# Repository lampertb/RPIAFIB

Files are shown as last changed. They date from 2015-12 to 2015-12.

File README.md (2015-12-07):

# RPIAFIB
AFIB Detection using Raspberry Pi Compute Module

This is a project created by Yifan Ge and Ben Lampert for the CS241 Embedded Workshop class(http://web.stanford.edu/class/cs241/). The intention is to create an open source AFIB detection wearable which can be used to diagnose patients with the condition.

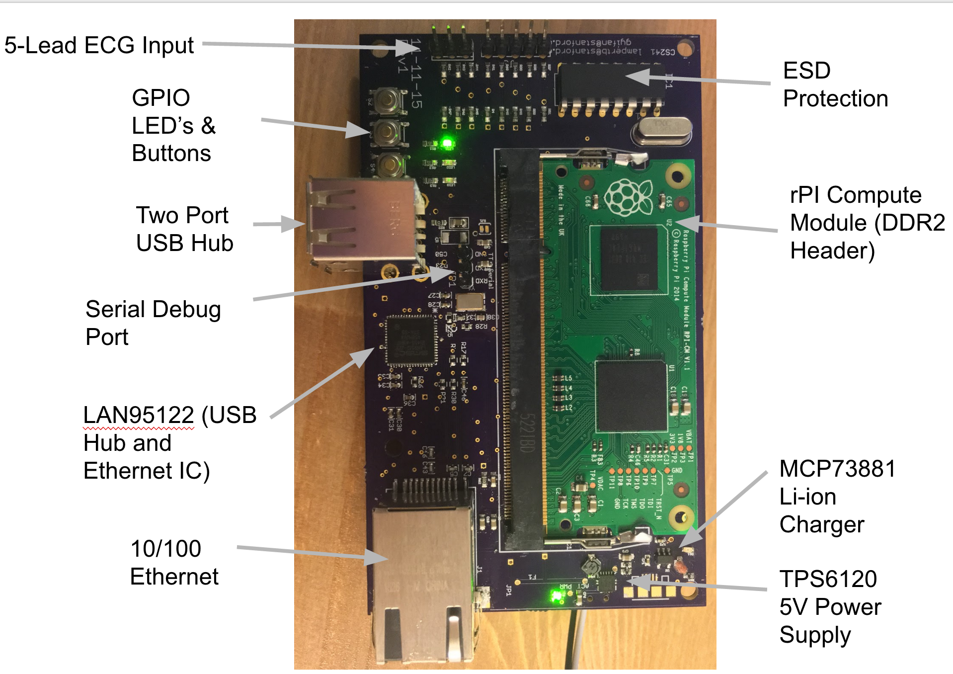
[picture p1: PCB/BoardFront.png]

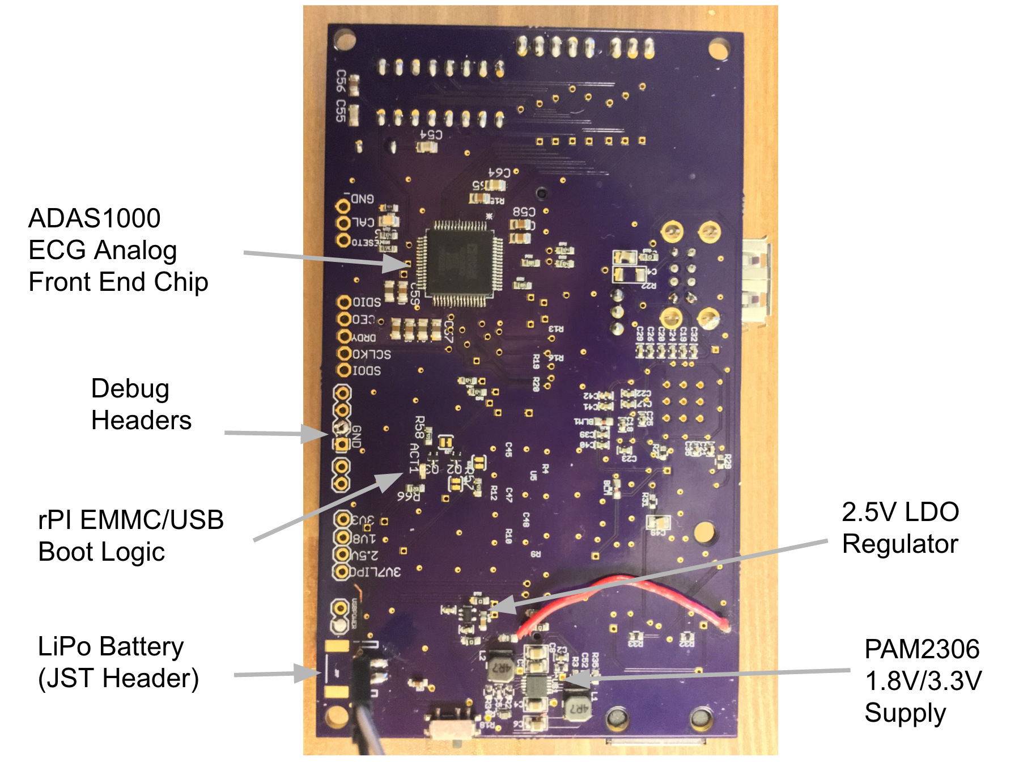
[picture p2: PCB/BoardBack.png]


Please reference the instructable for more information on assembling the board.
http://www.instructables.com/id/rPI-Atrial-Fibrillation-Detection-Board/

To install run

sudo sh ./install.sh

Run software:
cd Software
sudo ./execute_afib_detect

Todo:
Software:
-Improve ECG Capture code
-Improve integration between the algorithm detection and sampling code
Hardware:
-Lipo charger circuit does not allow for the board to be powered while charging the LED, need to find a solution for this. Integrated charger?

USE AT YOUR OWN RISK: This project involves ECG measurements which can be dangerous if not done correctly. It is your responsibility to evaluate your own medical and physical condition, or that of your clients, and to independently determine whether to perform, use or adapt any of the information or content on this repository. By voluntarily undertaking the project displayed on this website, you assume the risk of any resulting injury.

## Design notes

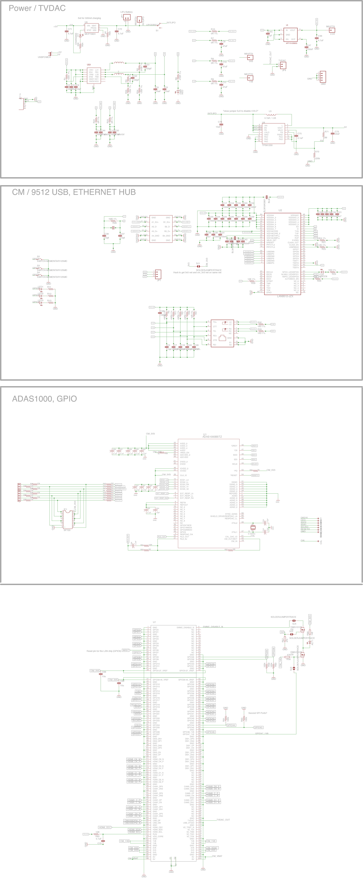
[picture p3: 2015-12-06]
PCB/Schematic.png

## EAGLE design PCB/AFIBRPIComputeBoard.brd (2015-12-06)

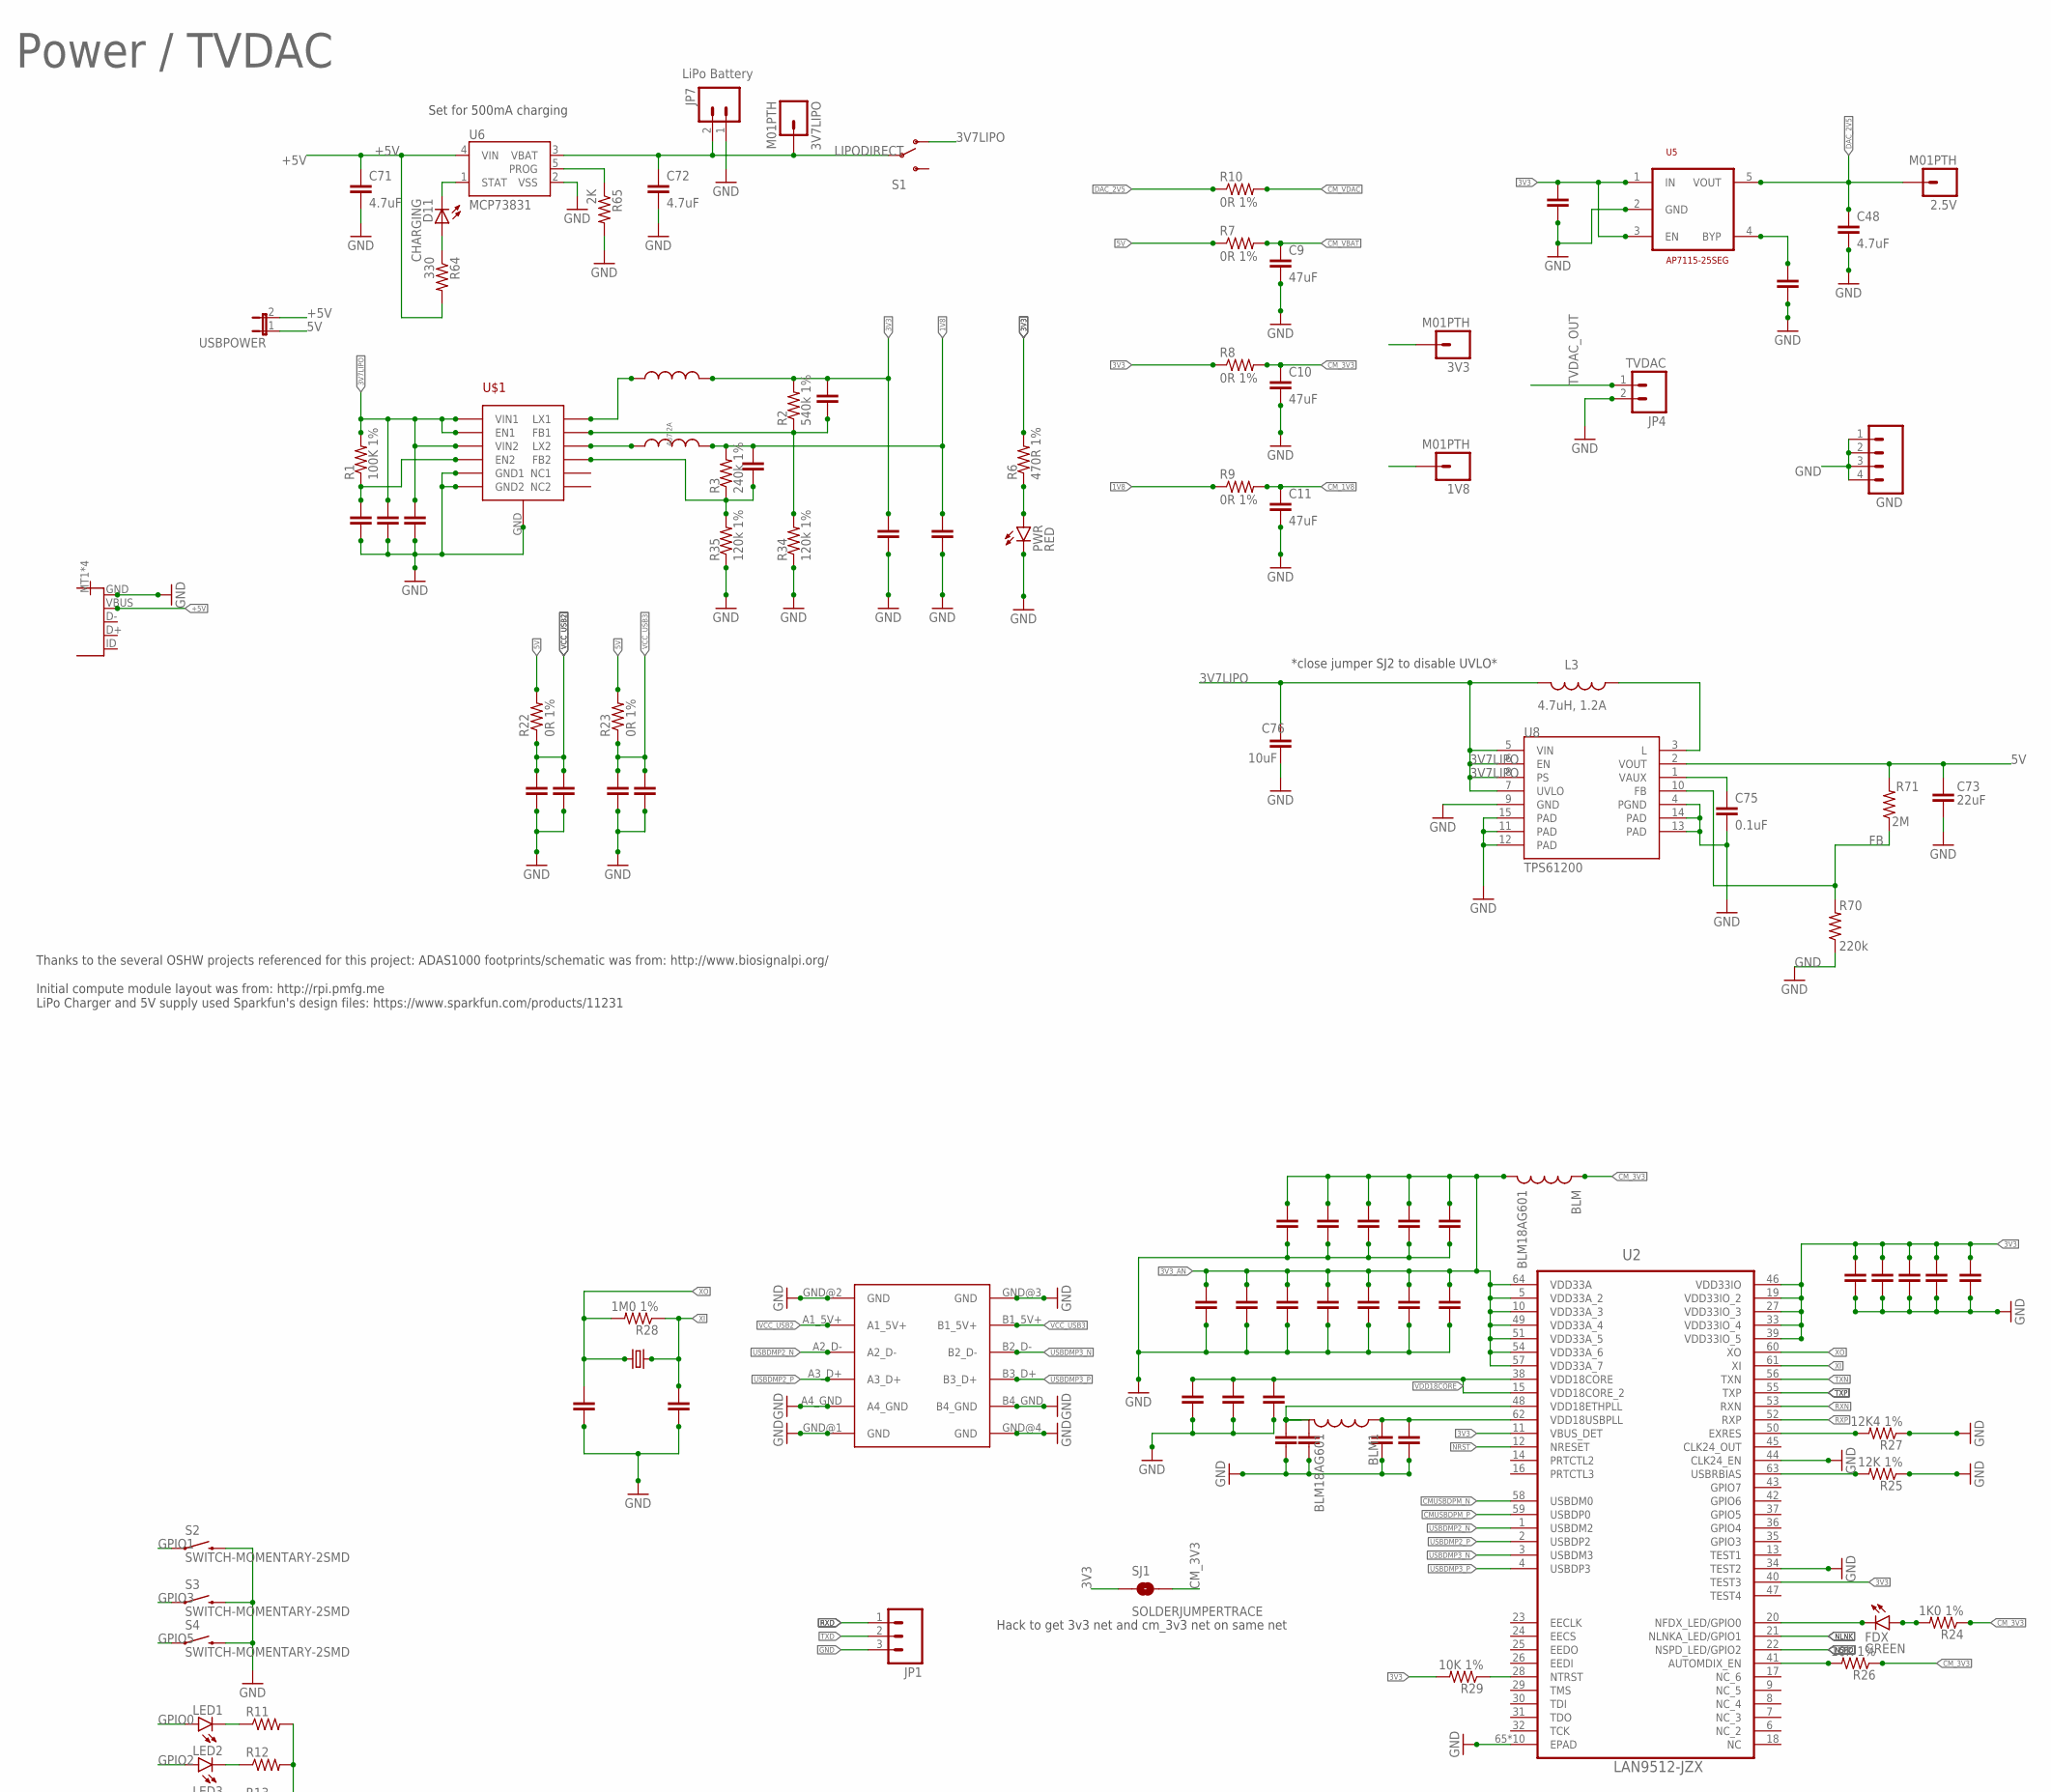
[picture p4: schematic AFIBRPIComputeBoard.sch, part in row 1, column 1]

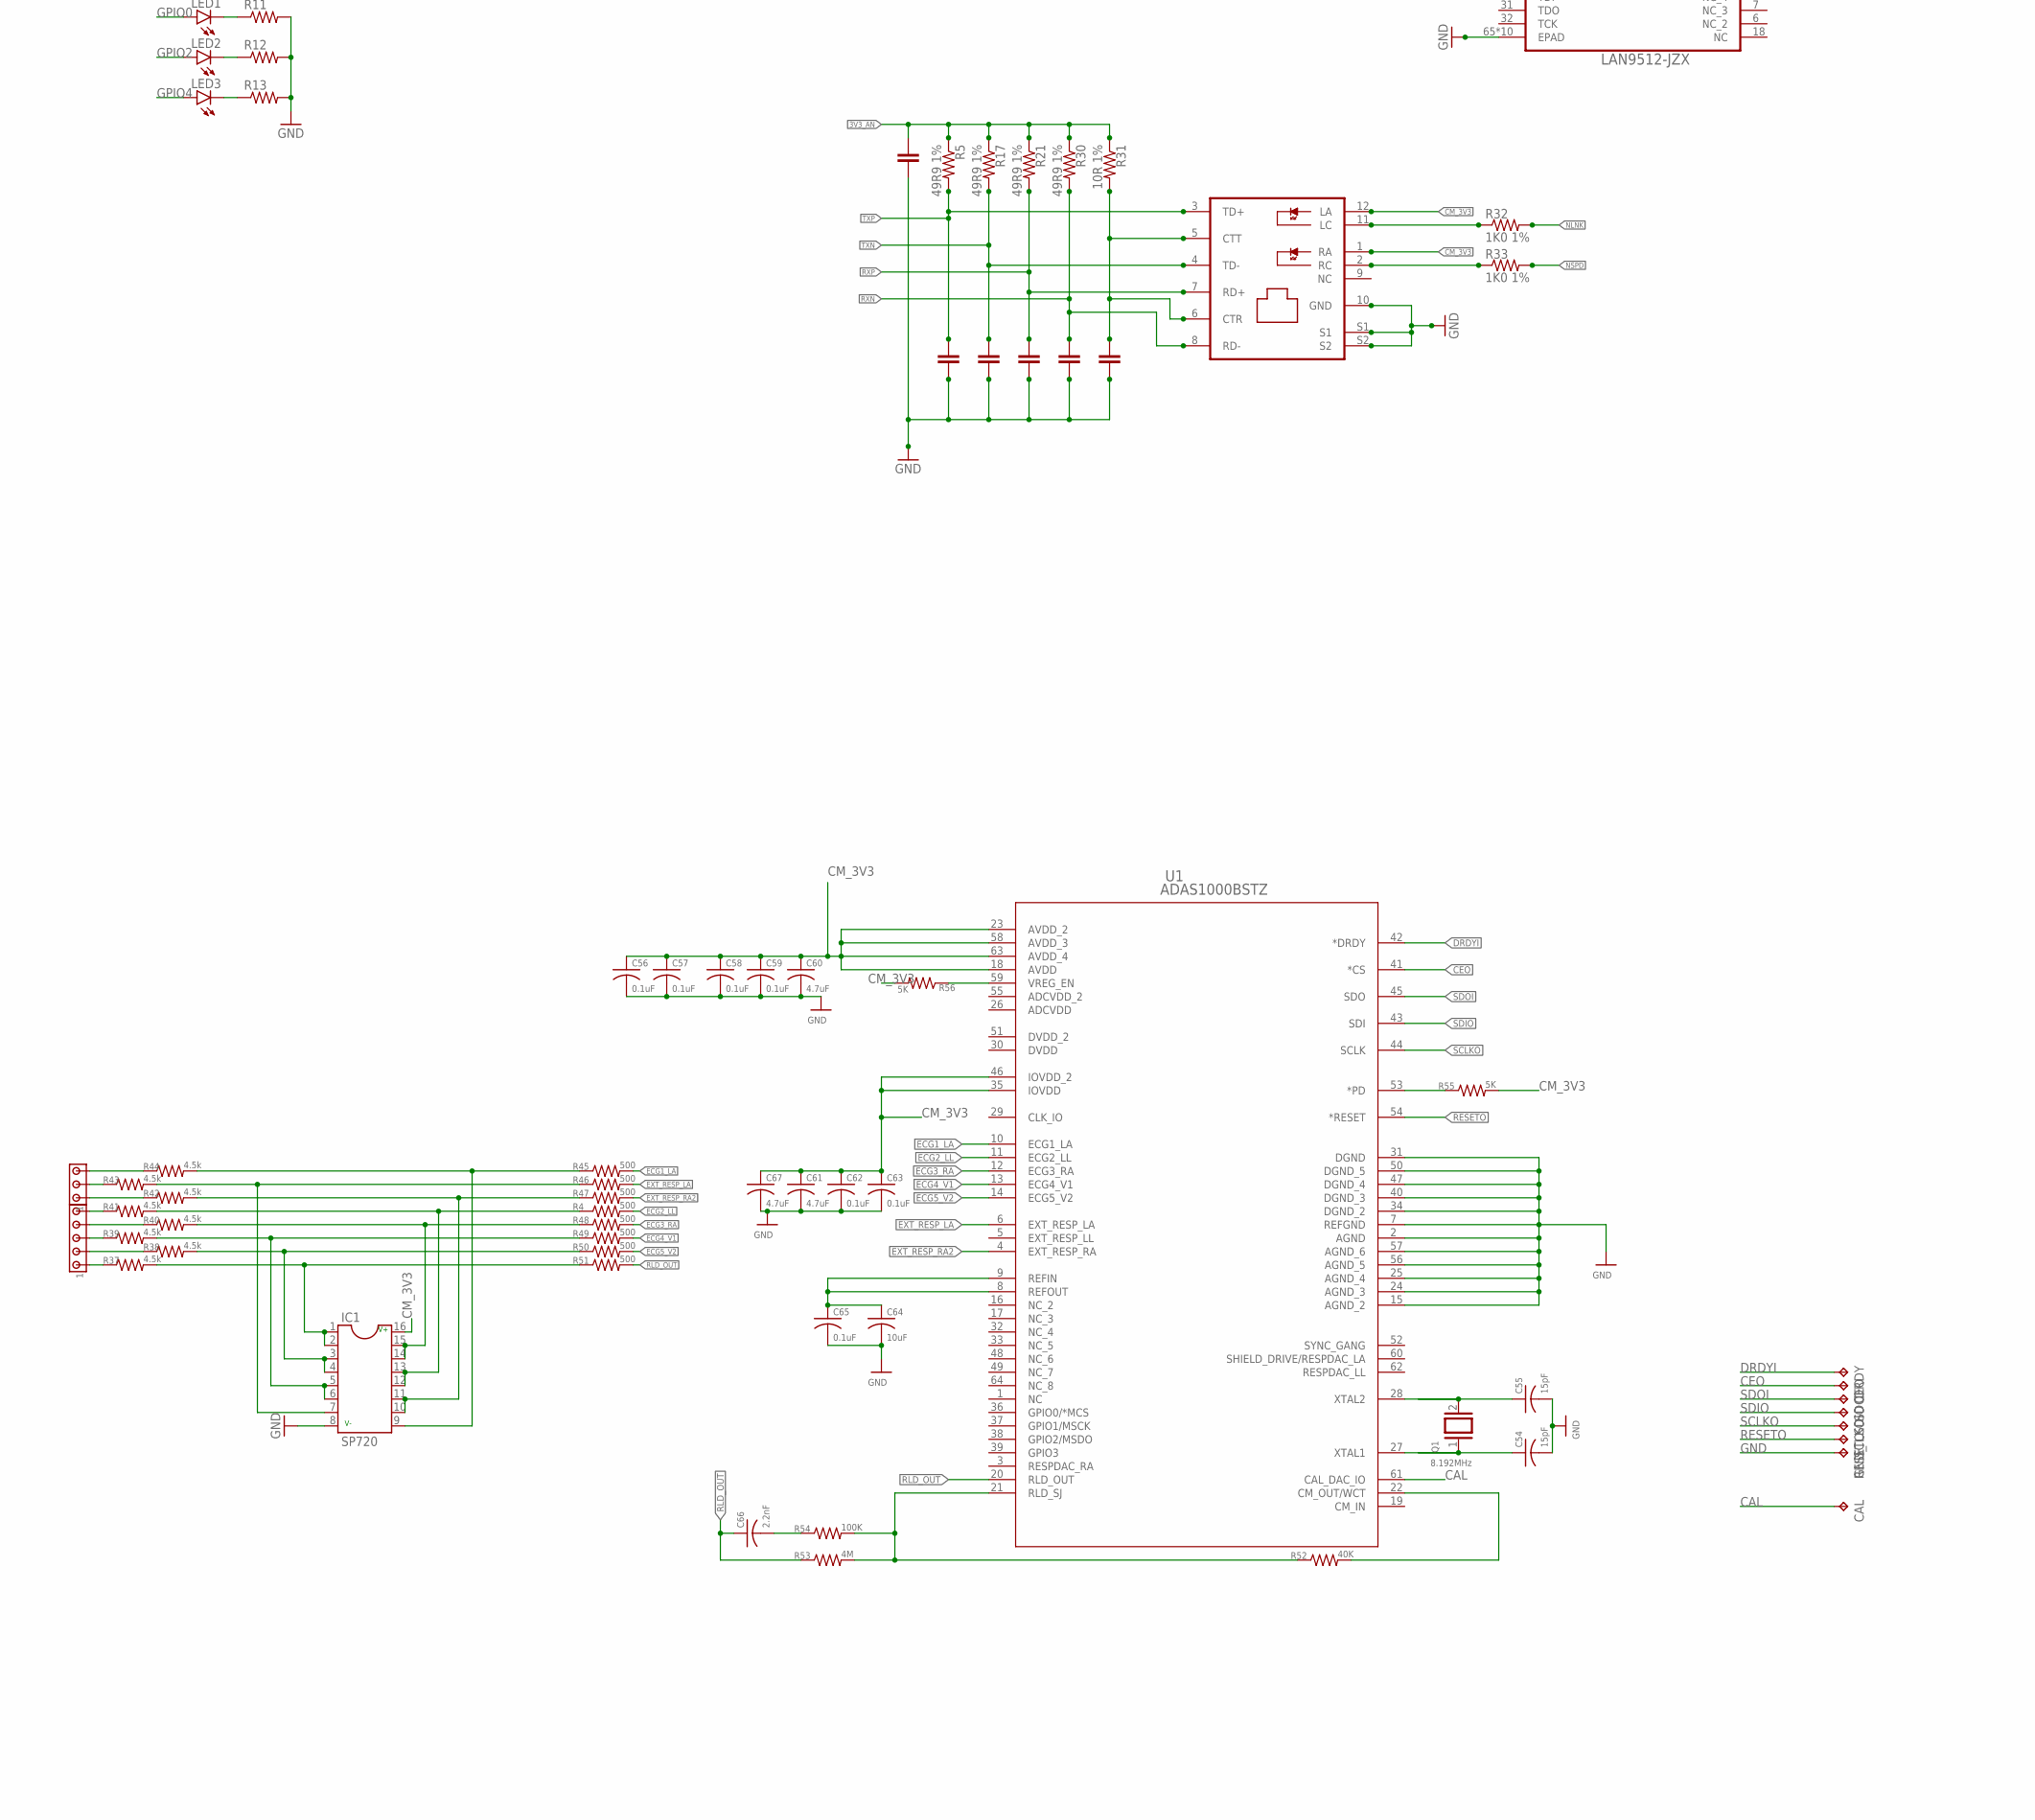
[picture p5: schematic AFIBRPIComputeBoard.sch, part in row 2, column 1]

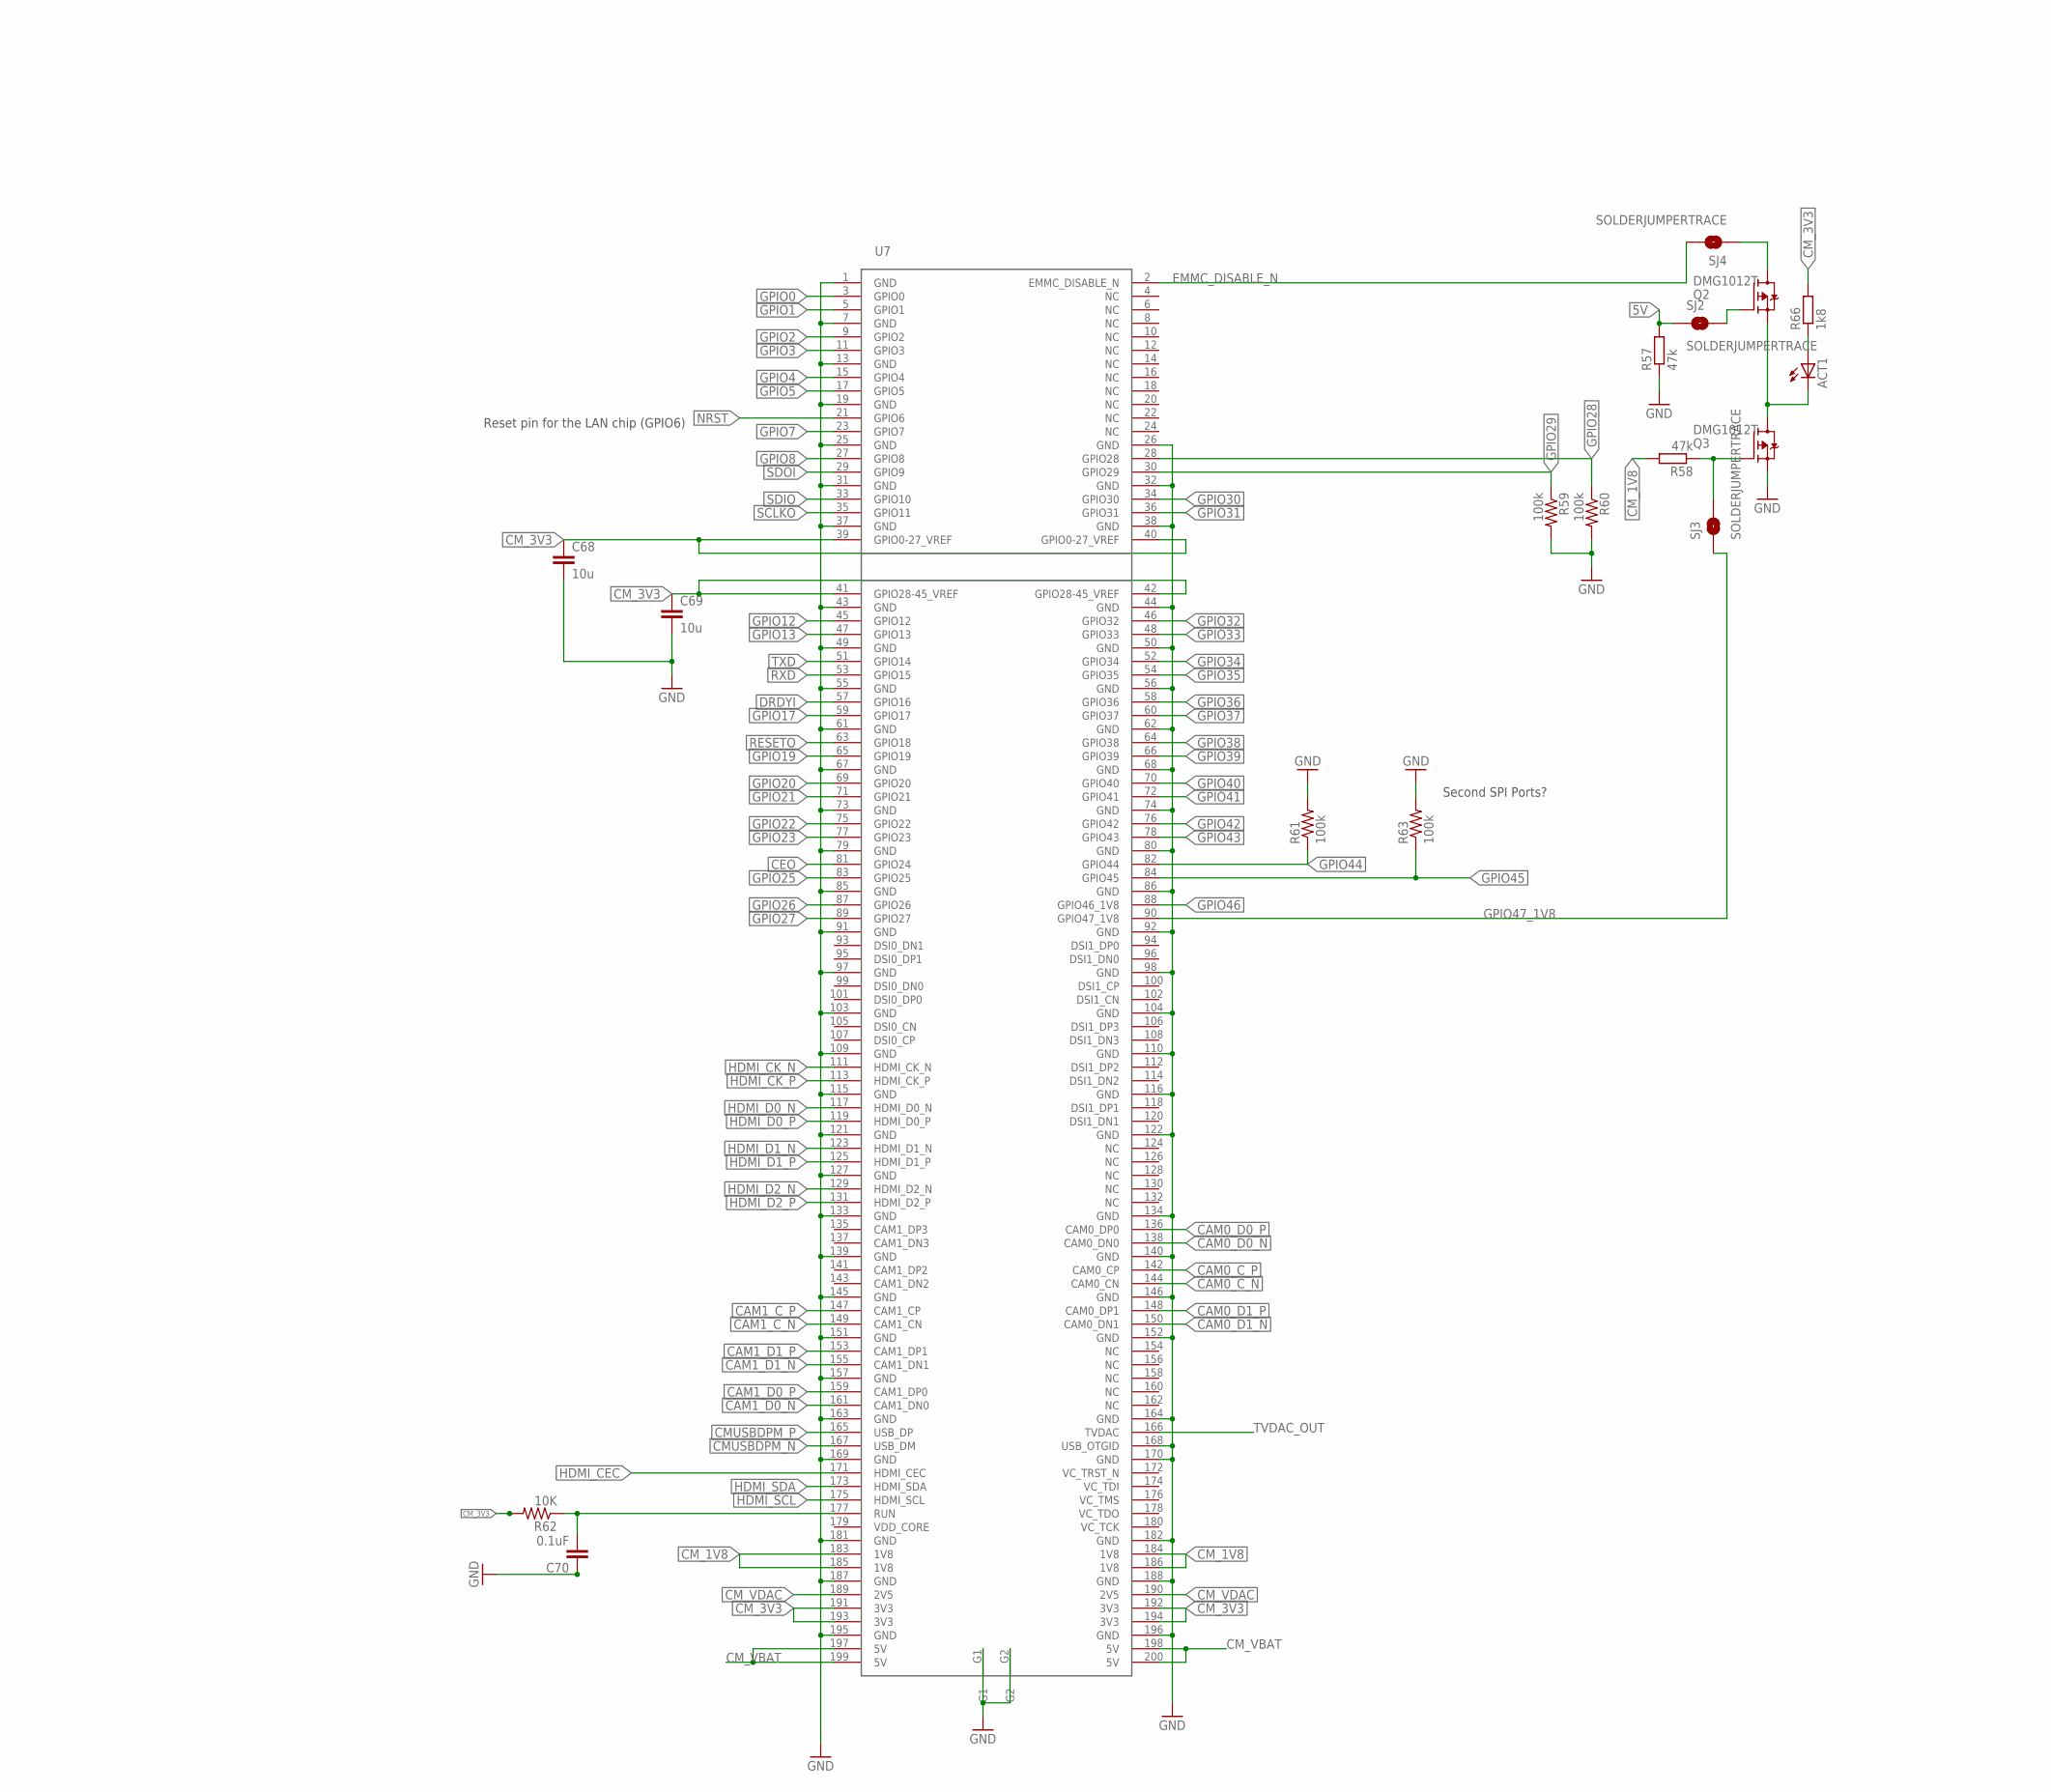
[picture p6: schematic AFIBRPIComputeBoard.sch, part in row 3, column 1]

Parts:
1V8, 2.5V, 3V3, 3V7LIPO: M01PTH; 1X01
ACT1: LEDCHIP-LED0603; CHIP-LED0603
BLM, BLM1: BLM18AG601; 0603
C2, C17, C18, C19, C20, C22, C23, C24, C25, C26, C27, C28, C29, C30, C31, C32, C33, C34, C35, C39, C40, C41, C42, C46, C47: 100nF; 0402
C3, C4, C6, C8: 10uF; 0805
C5, C7, C16, C43: 15pf 50V 5%; 0402
C9, C10, C11: 47uF; 0603-CAP
C14, C15: 100uF 10v; 1206
C21, C36: 4u7; 0402
C37, C38: 12pf; 0402
C44: 47uf 10v; 0805
C45: 1uF; 0402
C48: 4.7uF; 0603-CAP
C49: 22nF; 0805
C50: 47uF 10V; 0805
C51, C52: 100pF; 0402
C54, C55: 15pF; C0805
C56, C57, C58, C59, C62, C63, C65: 0.1uF; C0805
C60, C61, C67: 4.7uF; C0805
C64: 10uF; C0805
C66: 2.2nF; C0805
C68, C69: 10u; 0603-CAP
C70, C75: 0.1uF; 0603-CAP
C71, C72: 4.7uF; 0402-CAP
C73: 22uF; 0603-CAP
C76: 10uF; 0603-CAP
CAL: TPPAD1-13; P1-13
CEO: TPPAD1-13; P1-13
D11: CHARGING; LED-0603
DRDY: TPPAD1-13; P1-13
FDX: GREEN; LED-0603
GND: M04PTH; 1X04
GND_: TPPAD1-13; P1-13
IC1: SP720; DIL16
J1: J3011; J30
J2: JUMPERS; 10X03MTA
J3: JUMPERS; 10X05MTA
JP1: M03PTH; 1X03
JP3: USB-IDMICRO; USB-MICRO
JP4: TVDAC; 1X02
JP7: LiPo Battery; JST-2-SMD
L1, L2: 4.7u 2A; SRN4018
L3: 4.7uH, 1.2A; CDRH2D09
LED1, LED2, LED3: LED0603; LED-0603
PWR: RED; LED-0603
Q1: 8.192MHz; QS
Q2, Q3: DMG1012T; SC75_INFINEON
R1: 100K 1%; 0402-RES
R2: 540k 1%; 0402-RES
R3: 240k 1%; 0402-RES
R4, R45, R46, R47, R48, R49, R50, R51: 500; 0603-RES
R5, R17, R21, R30: 49R9 1%; 0402-RES
R6: 470R 1%; 0402-RES
R7, R8, R9, R10, R22, R23: 0R 1%; 0603-RES
R11, R12, R13: RESISTOR0603; 0603-RES
R24, R32, R33: 1K0 1%; 0402-RES
R25: 12K 1%; 0402-RES
R26, R29: 10K 1%; 0402-RES
R27: 12K4 1%; 0402-RES
R28: 1M0 1%; 0402-RES
R31: 10R 1%; 0402-RES
R34, R35: 120k 1%; 0402-RES
R37, R38, R39, R40, R41, R42, R43, R44: 4.5k; 0603-RES
R52: 40K; 0603-RES
R53: 4M; 0603-RES
R54: 100K; 0603-RES
R55, R56: 5K; 0603-RES
R57, R58: 47k; R0603
R59, R60, R61, R63: 100k; 0603-RES
R62: 10K; 0603-RES
R64: 330; 0402-RES
R65: 2K; 0402-RES
R66: 1k8; R0603
R70: 220k; 0402-RES
R71: 2M; 0402-RES
RESETO: TPPAD1-13; P1-13
S1: SWITCH-SPDT-SMD-A; SWITCH-SPST-SMD-A
S2, S3, S4: SWITCH-MOMENTARY-2SMD; TACTILE-SWITCH-SMD
SCLKO: TPPAD1-13; P1-13
SDIO: TPPAD1-13; P1-13
SDOI: TPPAD1-13; P1-13
SJ1, SJ2, SJ3, SJ4: SOLDERJUMPERTRACE; SJ_2S-TRACE
U1: ADAS1000BSTZ; ST_64_2
U2: LAN9512-JZX; QFN50P900X900X100-65N
U5: AP7115-25SEG; SOT353
U6: MCP73831; SOT23-5
U7: RASPI; SO-DIMM
U8: TPS61200; QFN-10_PAD
U$1: WDFN-12L
USB1: 72309USB-TYPE-A; 72309
USBPOWER: JUMPER-2PTH; 1X02
Y1: CRYSTAL5X3; CRYSTAL-SMD-5X3

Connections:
1V8: C8.1, C52.1, L2.P$2 (2), R3.2, R9.1
3V3: C6.1, C21.1, C32.1, C33.1, C34.1, C35.1, C45.1, C51.1, L1.P$2 (2), R2.2, R6.2, R8.1, R29.2, SJ1.1, U2.11 (VBUS_DET), U2.19 (VDD33IO_2), U2.27 (VDD33IO_3), U2.33 (VDD33IO_4), U2.39 (VDD33IO_5), U2.40 (TEST3), U2.46 (VDD33IO), U5.1 (IN), U5.3 (EN)
3V3_AN: BLM.2, C17.1, C18.1, C19.1, C20.1, C22.1, C23.1, C24.1, C25.1, C26.1, C27.1, C28.1, C29.1, C46.1, R5.1, R17.1, R21.1, R30.1, R31.1, U2.5 (VDD33A_2), U2.10 (VDD33A_3), U2.49 (VDD33A_4), U2.51 (VDD33A_5), U2.54 (VDD33A_6), U2.57 (VDD33A_7), U2.64 (VDD33A)
3V7LIPO: C3.1, C4.1, C76.1, L3.P$2 (2), R1.2, S1.1 (O), U8.5 (VIN), U8.6 (EN), U8.7 (UVLO), U8.8 (PS), U$1.1 (VIN2), U$1.6 (EN1), U$1.7 (VIN1)
5V: C73.1, R7.1, R22.2, R23.2, R57.2, R71.2, SJ2.1, U8.2 (VOUT), USBPOWER.1
+5V: C71.1, JP3.VBUS, R64.2, U6.4 (VIN), USBPOWER.2
CAL: CAL.TP, U1.61 (CAL_DAC_IO)
CAM0_C_N: U7.144 (CAM0_CN)
CAM0_C_P: U7.142 (CAM0_CP)
CAM0_D0_N: U7.138 (CAM0_DN0)
CAM0_D0_P: U7.136 (CAM0_DP0)
CAM0_D1_N: U7.150 (CAM0_DN1)
CAM0_D1_P: U7.148 (CAM0_DP1)
CAM1_C_N: U7.149 (CAM1_CN)
CAM1_C_P: U7.147 (CAM1_CP)
CAM1_D0_N: U7.161 (CAM1_DN0)
CAM1_D0_P: U7.159 (CAM1_DP0)
CAM1_D1_N: U7.155 (CAM1_DN1)
CAM1_D1_P: U7.153 (CAM1_DP1)
CEO: CEO.TP, U1.41 (*CS), U7.81 (GPIO24)
CMUSBDPM_N: U2.58 (USBDM0), U7.167 (USB_DM)
CMUSBDPM_P: U2.59 (USBDP0), U7.165 (USB_DP)
CM_1V8: 1V8.1, C11.1, R9.2, R58.2, U7.183 (1V8), U7.184 (1V8), U7.185 (1V8), U7.186 (1V8)
CM_3V3: 3V3.1, BLM.1, C10.1, C56.1, C57.1, C58.1, C59.1, C60.1, C61.1, C62.1, C63.1, C67.1, C68.1, C69.1, IC1.16, J1.1 (RA), J1.12 (LA), R8.2, R24.1, R26.1, R55.2, R56.2, R62.2, R66.2, SJ1.2, U1.18 (AVDD), U1.23 (AVDD_2), U1.35 (IOVDD), U1.46 (IOVDD_2), U1.58 (AVDD_3), U1.63 (AVDD_4), U7.39 (GPIO0-27_VREF), U7.40 (GPIO0-27_VREF), U7.41 (GPIO28-45_VREF), U7.42 (GPIO28-45_VREF), U7.191 (3V3), U7.192 (3V3), U7.193 (3V3), U7.194 (3V3)
CM_VBAT: C9.1, R7.2, U7.197 (5V), U7.198 (5V), U7.199 (5V), U7.200 (5V)
CM_VDAC: R10.2, U7.189 (2V5), U7.190 (2V5)
DAC_2V5: 2.5V.1, C48.1, R10.1, U5.5 (VOUT)
DRDYI: DRDY.TP, U1.42 (*DRDY), U7.57 (GPIO16)
ECG1_LA: R45.2, U1.10 (ECG1_LA)
ECG2_LL: R4.2, U1.11 (ECG2_LL)
ECG3_RA: R48.2, U1.12 (ECG3_RA)
ECG4_V1: R49.2, U1.13 (ECG4_V1)
ECG5_V2: R50.2, U1.14 (ECG5_V2)
EMMC_DISABLE_N: SJ4.2, U7.2 (EMMC_DISABLE_N)
EXT_RESP_LA: R46.2, U1.6 (EXT_RESP_LA)
EXT_RESP_RA2: R47.2, U1.4 (EXT_RESP_RA)
FB: R70.2, R71.1, U8.10 (FB)
GND: C2.2, C3.2, C4.2, C5.2, C6.2, C7.2, C8.2, C9.2, C10.2, C11.2, C14.2, C15.2, C16.2, C17.2, C18.2, C19.2, C20.2, C21.2, C22.2, C23.2, C24.2, C25.2, C26.2, C27.2, C28.2, C29.2, C30.2, C31.2, C32.2, C33.2, C34.2, C35.2, C36.2, C37.2, C38.2, C39.2, C40.2, C41.2, C42.2, C43.2, C44.2, C45.2, C46.2, C47.2, C48.2, C49.2, C50.2, C54.2, C55.2, C56.2, C57.2, C58.2, C59.2, C60.2, C61.2, C62.2, C63.2, C64.2, C65.2, C67.2, C68.2, C69.2, C70.1, C71.2, C72.2, C73.2, C75.2, C76.2, GND.1, GND.2, GND.3, GND.4, GND_.TP, IC1.8, J1.10 (GND), J1.S1, J1.S2, JP1.3, JP3.GND, JP4.2, JP7.1, Q3.3 (S), R11.2, R12.2, R13.2, R25.1, R27.1, R34.1, R35.1, R57.1, R59.2, R60.2, R61.2, R63.2, R65.2, R70.1, S2.3 (2), S3.3 (2), S4.3 (2), U1.2 (AGND), U1.7 (REFGND), U1.15 (AGND_2), U1.24 (AGND_3), U1.25 (AGND_4), U1.31 (DGND), U1.34 (DGND_2), U1.40 (DGND_3), U1.47 (DGND_4), U1.50 (DGND_5), U1.56 (AGND_5), U1.57 (AGND_6), U2.34 (TEST2), U2.44 (CLK24_EN), U2.65 (EPAD), U2.GND@1 (EPAD), U2.GND@2 (EPAD), U2.GND@3 (EPAD), U2.GND@4 (EPAD), U2.GND@5 (EPAD), U2.GND@6 (EPAD), U2.GND@7 (EPAD), U2.GND@8 (EPAD), U2.GND@9 (EPAD), U5.2 (GND), U6.2 (VSS), U7.1 (GND), U7.7 (GND), U7.13 (GND), U7.19 (GND), U7.25 (GND), U7.26 (GND), U7.31 (GND), U7.32 (GND), U7.37 (GND), U7.38 (GND), U7.43 (GND), U7.44 (GND), U7.49 (GND), U7.50 (GND), U7.55 (GND), U7.56 (GND), U7.61 (GND), U7.62 (GND), U7.67 (GND), U7.68 (GND), U7.73 (GND), U7.74 (GND), U7.79 (GND), U7.80 (GND), U7.85 (GND), U7.86 (GND), U7.91 (GND), U7.92 (GND), U7.97 (GND), U7.98 (GND), U7.103 (GND), U7.104 (GND), U7.109 (GND), U7.110 (GND), U7.115 (GND), U7.116 (GND), U7.121 (GND), U7.122 (GND), U7.127 (GND), U7.133 (GND), U7.134 (GND), U7.139 (GND), U7.140 (GND), U7.145 (GND), U7.146 (GND), U7.151 (GND), U7.152 (GND), U7.157 (GND), U7.163 (GND), U7.164 (GND), U7.168 (USB_OTGID), U7.169 (GND), U7.170 (GND), U7.181 (GND), U7.182 (GND), U7.187 (GND), U7.188 (GND), U7.195 (GND), U7.196 (GND), U7.G1, U7.G2, U8.4 (PGND), U8.9 (GND), U8.11 (PAD), U8.12 (PAD), U8.13 (PAD), U8.14 (PAD), U8.15 (PAD), U$1.3 (GND1), U$1.9 (GND2), U$1.GND, USB1.A4_GND, USB1.B4_GND, USB1.GND@1 (GND), USB1.GND@2 (GND), USB1.GND@3 (GND), USB1.GND@4 (GND)
GPIO0: LED1.A, U7.3 (GPIO0)
GPIO1: S2.1, U7.5 (GPIO1)
GPIO2: LED2.A, U7.9 (GPIO2)
GPIO3: S3.1, U7.11 (GPIO3)
GPIO4: LED3.A, U7.15 (GPIO4)
GPIO5: S4.1, U7.17 (GPIO5)
GPIO7: U7.23 (GPIO7)
GPIO8: U7.27 (GPIO8)
GPIO12: U7.45 (GPIO12)
GPIO13: U7.47 (GPIO13)
GPIO17: U7.59 (GPIO17)
GPIO19: U7.65 (GPIO19)
GPIO20: U7.69 (GPIO20)
GPIO21: U7.71 (GPIO21)
GPIO22: U7.75 (GPIO22)
GPIO23: U7.77 (GPIO23)
GPIO25: U7.83 (GPIO25)
GPIO26: U7.87 (GPIO26)
GPIO27: U7.89 (GPIO27)
GPIO28: R60.1, U7.28 (GPIO28)
GPIO29: R59.1, U7.30 (GPIO29)
GPIO30: U7.34 (GPIO30)
GPIO31: U7.36 (GPIO31)
GPIO32: U7.46 (GPIO32)
GPIO33: U7.48 (GPIO33)
GPIO34: U7.52 (GPIO34)
GPIO35: U7.54 (GPIO35)
GPIO36: U7.58 (GPIO36)
GPIO37: U7.60 (GPIO37)
GPIO38: U7.64 (GPIO38)
GPIO39: U7.66 (GPIO39)
GPIO40: U7.70 (GPIO40)
GPIO41: U7.72 (GPIO41)
GPIO42: U7.76 (GPIO42)
GPIO43: U7.78 (GPIO43)
GPIO44: R61.1, U7.82 (GPIO44)
GPIO45: R63.1, U7.84 (GPIO45)
GPIO46: U7.88 (GPIO46_1V8)
GPIO47_1V8: SJ3.1, U7.90 (GPIO47_1V8)
HDMI_CEC: U7.171 (HDMI_CEC)
HDMI_CK_N: U7.111 (HDMI_CK_N)
HDMI_CK_P: U7.113 (HDMI_CK_P)
HDMI_D0_N: U7.117 (HDMI_D0_N)
HDMI_D0_P: U7.119 (HDMI_D0_P)
HDMI_D1_N: U7.123 (HDMI_D1_N)
HDMI_D1_P: U7.125 (HDMI_D1_P)
HDMI_D2_N: U7.129 (HDMI_D2_N)
HDMI_D2_P: U7.131 (HDMI_D2_P)
HDMI_SCL: U7.175 (HDMI_SCL)
HDMI_SDA: U7.173 (HDMI_SDA)
JUMPERS: J2.1, R42.1
LIPODIRECT: 3V7LIPO.1, C72.1, JP7.2, S1.2, U6.3 (VBAT)
unnamed: L1.P$1 (1), U$1.8 (LX1)
unnamed: C51.2, R2.1, R34.2, U$1.4 (FB1)
unnamed: C2.1, R1.1, U$1.12 (EN2)
unnamed: L2.P$1 (1), U$1.2 (LX2)
unnamed: C52.2, R3.1, R35.2, U$1.10 (FB2)
unnamed: PWR.A, R6.1
unnamed: Q2.2 (D), SJ4.1
unnamed: Q3.1 (G), R58.1, SJ3.2
unnamed: LED3.C, R13.1
unnamed: LED2.C, R12.1
unnamed: FDX.A, R24.2
unnamed: LED1.C, R11.1
unnamed: Q2.1 (G), SJ2.2
unnamed: R25.2, U2.63 (USBRBIAS)
unnamed: J3.1, R37.1
unnamed: C47.1, U5.4 (BYP)
unnamed: BLM1.1, C41.1, C42.1, U2.62 (VDD18USBPLL)
unnamed: BLM1.2, C39.1, C40.1, U2.48 (VDD18ETHPLL)
unnamed: R26.2, U2.41 (AUTOMDIX_EN)
unnamed: R27.2, U2.50 (EXRES)
unnamed: R29.1, U2.28 (NTRST)
unnamed: J1.11 (LC), R32.1
unnamed: J1.2 (RC), R33.1
unnamed: C49.1, J1.5 (CTT), J1.6 (CTR), R31.2
unnamed: FDX.C, U2.20 (NFDX_LED/GPIO0)
unnamed: J3.2, R38.1
unnamed: J3.3, R39.1
unnamed: J3.4, R40.1
unnamed: J3.5, R41.1
unnamed: J2.2, R43.1
unnamed: J2.3, R44.1
unnamed: IC1.9, R44.2, R45.1
unnamed: IC1.7, R43.2, R46.1
unnamed: IC1.3, IC1.4, R38.2, R50.1
unnamed: IC1.5, IC1.6, R39.2, R49.1
unnamed: IC1.1, IC1.2, R37.2, R51.1
unnamed: IC1.14, IC1.15, R40.2, R48.1
unnamed: IC1.12, IC1.13, R4.1, R41.2
unnamed: IC1.10, IC1.11, R42.2, R47.1
unnamed: C55.1, Q1.2, U1.28 (XTAL2)
unnamed: C54.1, Q1.1, U1.27 (XTAL1)
unnamed: C66.2, R54.1
unnamed: R55.1, U1.53 (*PD)
unnamed: R56.1, U1.59 (VREG_EN)
unnamed: R52.2, U1.22 (CM_OUT/WCT)
unnamed: C64.1, C65.1, U1.8 (REFOUT), U1.9 (REFIN)
unnamed: R52.1, R53.2, R54.2, U1.21 (RLD_SJ)
unnamed: ACT1.C, Q2.3 (S), Q3.2 (D)
unnamed: D11.A, R64.1
unnamed: L3.P$1 (1), U8.3 (L)
unnamed: C75.1, U8.1 (VAUX)
unnamed: ACT1.A, R66.1
NLNK: R32.2, U2.21 (NLNKA_LED/GPIO1)
NRST: U2.12 (NRESET), U7.21 (GPIO6)
NSPD: R33.2, U2.22 (NSPD_LED/GPIO2)
PROG: R65.1, U6.5 (PROG)
RESETO: RESETO.TP, U1.54 (*RESET), U7.63 (GPIO18)
RLD_OUT: C66.1, R51.2, R53.1, U1.20 (RLD_OUT)
RUNPIN: C70.2, R62.1, U7.177 (RUN)
RXD: JP1.1, U7.53 (GPIO15)
RXN: C43.1, J1.8 (RD-), R30.2, U2.53 (RXN)
RXP: C16.1, J1.7 (RD+), R21.2, U2.52 (RXP)
SCLKO: SCLKO.TP, U1.44 (SCLK), U7.35 (GPIO11)
SDIO: SDIO.TP, U1.43 (SDI), U7.33 (GPIO10)
SDOI: SDOI.TP, U1.45 (SDO), U7.29 (GPIO9)
STAT: D11.C, U6.1 (STAT)
TVDAC_OUT: JP4.1, U7.166 (TVDAC)
TXD: JP1.2, U7.51 (GPIO14)
TXN: C7.1, J1.4 (TD-), R17.2, U2.56 (TXN)
TXP: C5.1, J1.3 (TD+), R5.2, U2.55 (TXP)
USBDMP2_N: U2.1 (USBDM2), USB1.A2_D-
USBDMP2_P: U2.2 (USBDP2), USB1.A3_D+
USBDMP3_N: U2.3 (USBDM3), USB1.B2_D-
USBDMP3_P: U2.4 (USBDP3), USB1.B3_D+
VCC_USB2: C14.1, C44.1, R22.1, USB1.A1_5V+
VCC_USB3: C15.1, C50.1, R23.1, USB1.B1_5V+
VDD18CORE: C30.1, C31.1, C36.1, U2.15 (VDD18CORE_2), U2.38 (VDD18CORE)
XI: C37.1, R28.1, U2.61 (XI), Y1.3 (2)
XO: C38.1, R28.2, U2.60 (XO), Y1.1

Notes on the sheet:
Power / TVDAC
Second SPI Ports?
Reset pin for the LAN chip (GPIO6)
Set for 500mA charging
*close jumper SJ2 to disable UVLO*
Hack to get 3v3 net and cm_3v3 net on same net
Thanks to the several OSHW projects referenced for this project: ADAS1000 footprints/schematic was from: http://www.biosignalpi.org/ Initial compute module layout was from: http://rpi.pmfg.me LiPo Charger and 5V supply used Sparkfun's design files: https://www.sparkfun.com/products/11231

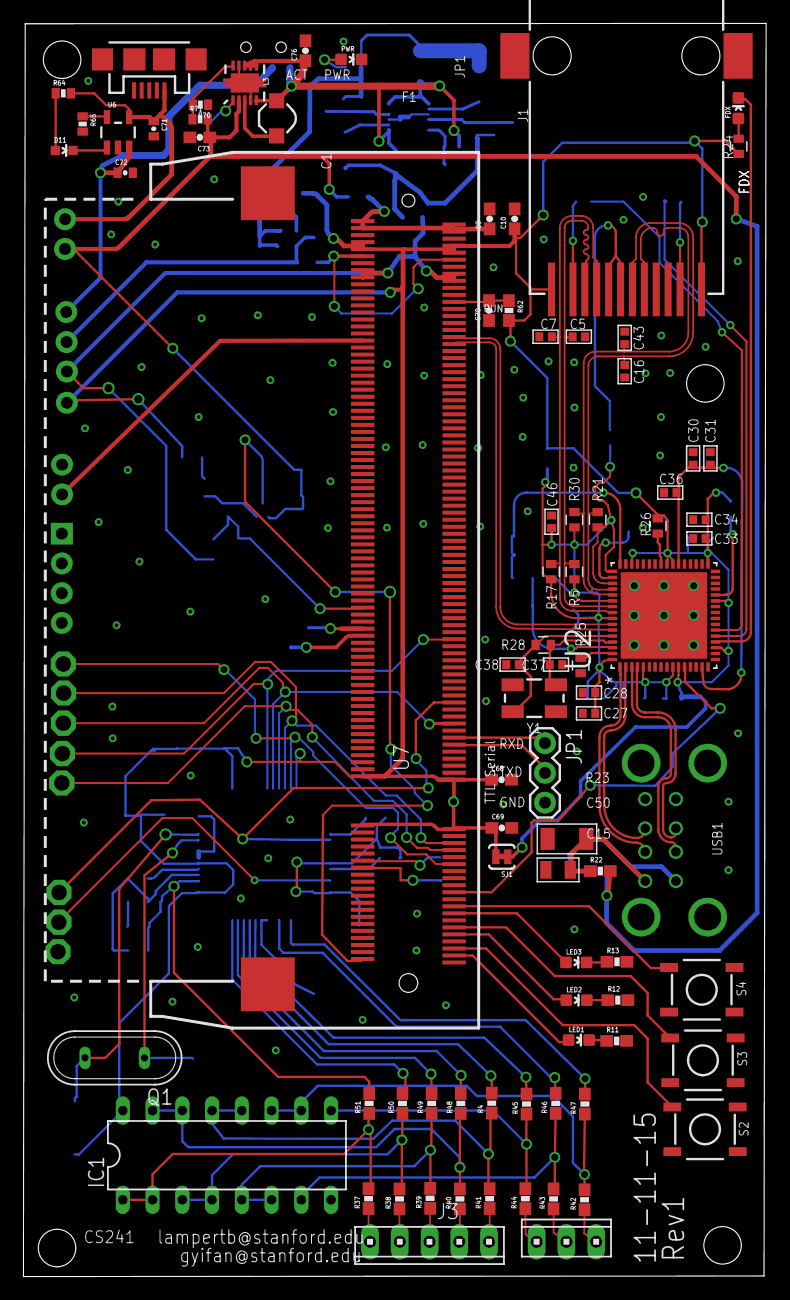
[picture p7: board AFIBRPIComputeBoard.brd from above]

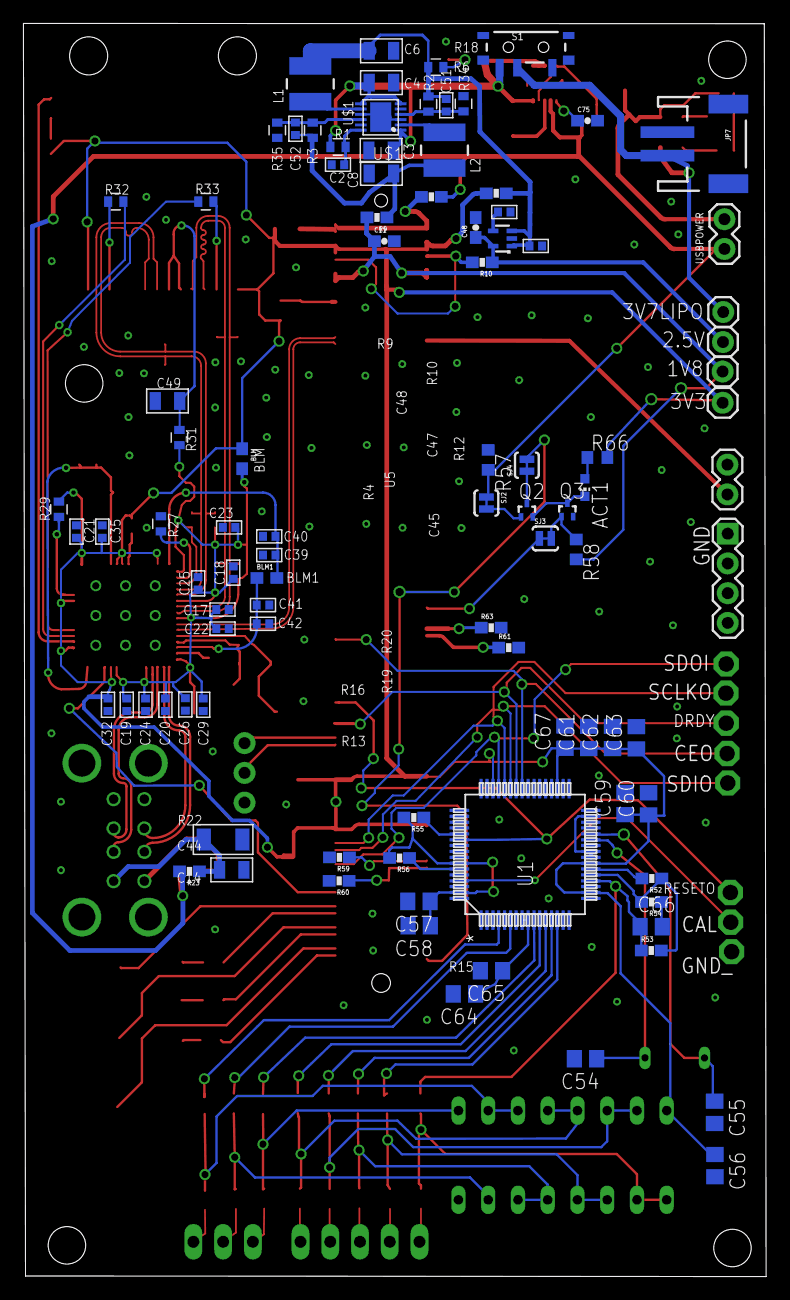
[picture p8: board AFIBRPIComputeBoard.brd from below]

Board: 2 copper layers, 63.4 x 107.0 mm, 186 parts (103 on the bottom side), 118 nets.

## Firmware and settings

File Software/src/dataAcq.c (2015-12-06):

#include "dataAcq.h"

void spiSetup (int speed)
{
	if ((myFd = wiringPiSPISetup (SPI_CHAN, speed)) < 0)
	{
		fprintf (stderr, "Can't open the SPI bus: %s\n", strerror (errno)) ;
		exit (EXIT_FAILURE) ;
	}
}

void sendMessage(uint32_t message){

	int size ;
	int spiFail ;
	unsigned char myData[4] ;

	spiFail = FALSE ;

	myData[0] = (message & 0xFF000000) >> 24;
	myData[1] = (message & 0x00FF0000) >> 16;
	myData[2] = (message & 0x0000FF00) >> 8;
	myData[3] = (message & 0x000000FF);

	size=4;
	if (wiringPiSPIDataRW (SPI_CHAN, myData, size) == -1)
	{
		printf ("SPI failure: %s\n", strerror (errno)) ;
		spiFail = TRUE ;
	}
}

int rcvMsg(uint32_t* message){

	int spiFail ;
	unsigned char myData[4] ;

	spiFail = FALSE ;

	myData[0] = (*message & 0xFF000000) >> 24;
	myData[1] = (*message & 0x00FF0000) >> 16;
	myData[2] = (*message & 0x0000FF00) >> 8;
	myData[3] = (*message & 0x000000FF);

	if (wiringPiSPIDataRW (SPI_CHAN, myData, PKT_SIZE) == -1)
	{
		printf ("SPI failure: %s\n", strerror (errno)) ;
		spiFail = TRUE ;
	}

  *message = myData[0];
  *message = (*message << 8) | myData[1];
  *message = (*message << 8) | myData[2];
  *message = (*message << 8) | myData[3];

  int retval = rdval(*message);

  return retval;
}

int rdval(uint32_t msg){
  int retval;
  
  unsigned char sign;
  unsigned char lead;
  
  lead = (msg & 0xFF000000) >> 24;
  sign = (msg & 0x00800000) >> 23;
  
  if (sign == 1)
    retval = msg | 0xFF000000;
  else
    retval = msg & 0x00FFFFFF;
  retval -= 100;
  
  return retval;
}

void init_adas_spi()
{
  int speed = 2;
	wiringPiSetup () ;

  pinMode(NRST_PIN, OUTPUT);
  digitalWrite(NRST_PIN, LOW);
  digitalWrite(NRST_PIN, HIGH);
  sleep(1);

	spiSetup (speed * 1000000) ;

  sendMessage(0x85E0004A);
  sendMessage(0x8B000000);
  sendMessage(0x8A1FC60C);
  sendMessage(0x81F800AE);
  sendMessage(0x83002099);
  sendMessage(0x82000015);
}

void rd_frame(int * data)
{
  uint32_t msg;
  sendMessage(0x40000000);
  msg = 0x11000000;
  data[0] = rcvMsg(&msg);
  msg = 0x12000000;
  data[1] = rcvMsg(&msg);
  msg = 0x13000000;
  data[2] = rcvMsg(&msg);
  msg = 0x00000000;
  data[3] = rcvMsg(&msg);
}

void clean_up()
{
	close (myFd) ;
}

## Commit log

2015-12-06 Added PCB layout
    [AFIBRPIComputeBoard.brd, AFIBRPIComputeBoard.sch]
2015-12-06 Added images of board and updated the readme

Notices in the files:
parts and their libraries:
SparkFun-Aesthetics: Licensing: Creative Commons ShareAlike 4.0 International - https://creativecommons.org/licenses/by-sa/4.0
